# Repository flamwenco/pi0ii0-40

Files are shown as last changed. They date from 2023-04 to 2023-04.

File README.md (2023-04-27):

# pi0ii0-40
Open source, RP2040 based pcb for the [M0ii040](https://booth.pm/ja/items/4407257).

Supported layout options:

m0ii40layout

## Production files

The current version of this pcb that supports all above layouts has been ordered and confirmed to work, but I am not responsible for your orders with a pcb manu. No support will be provided, order at your own risk.

## Special Thanks
[SST60](https://github.com/dededecline/SST60), this project heavily lifts the rp2040 wiring from it

[marksard's](https://github.com/marksard/ms_m0ii040pcb) m0ii040 pcb, used to sanity check my edge cuts

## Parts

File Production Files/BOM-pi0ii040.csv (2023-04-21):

Comment | Designator | Footprint | LCSC
1k | R_Crystal1,R_Flash1,R_RST1 | R_0402_1005Metric | C11702
PRTR5V0U2X | U3 | SOT143B | C12333
.1u | C_1V-Decoup2,C_1V-Decoup3,C_3V-Decoup3,C_3V-Decoup4,C_3V-Decoup5,C_3V-Decoup6,C_3V-Decoup7,C_3V-Decoup8,C_3V-Decoup9,C_Flash1 | C_0402_1005Metric | C1525
10u | C_3V-Decoup1 | C_0402_1005Metric | C15525
22pF | C_Crystal1,C_Crystal2 | C_0402_1005Metric | C1555
HRO-TYPE-C-31-M-12 | USB1 | HRO-TYPE-C-31-M-12-Assembly | C165948
27 | R_DATA1,R_DATA2 | R_0402_1005Metric | C203147
RP2040 | U1 | RP2040-QFN-56 | C2040
4.7n | C_Shield1 | C_0402_1005Metric | C237221
5k1 | R_USB1,R_USB2 | R_0402_1005Metric | C25905
1M | R_Shield1 | R_0402_1005Metric | C26083
1u | C_1V-Decoup1,C_3V-Decoup2,C_LDO1,C_LDO2 | C_0402_1005Metric | C52923
XC6206PxxxMR | U4 | SOT-23 | C5446
D_Small | D1,D10,D11,D12,D13,D14,D15,D16,D17,D18,D19,D2,D20,D21,D22,D23,D24,D25,D26,D27,D28,D29,D3,D30,D31,D32,D33,D34,D35,D36,D37,D38,D39,D4,D40,D5,D6,D7,D8,D9 | D_SOD-123 | C64898
12MHz | Y1 | Crystal_SMD_3225-4Pin_3.2x2.5mm | C9002
W25Q128JVS | U2 | SOIC-8_5.23x5.23mm_P1.27mm | C97521
500mA | F1 | Fuse_0805_2012Metric

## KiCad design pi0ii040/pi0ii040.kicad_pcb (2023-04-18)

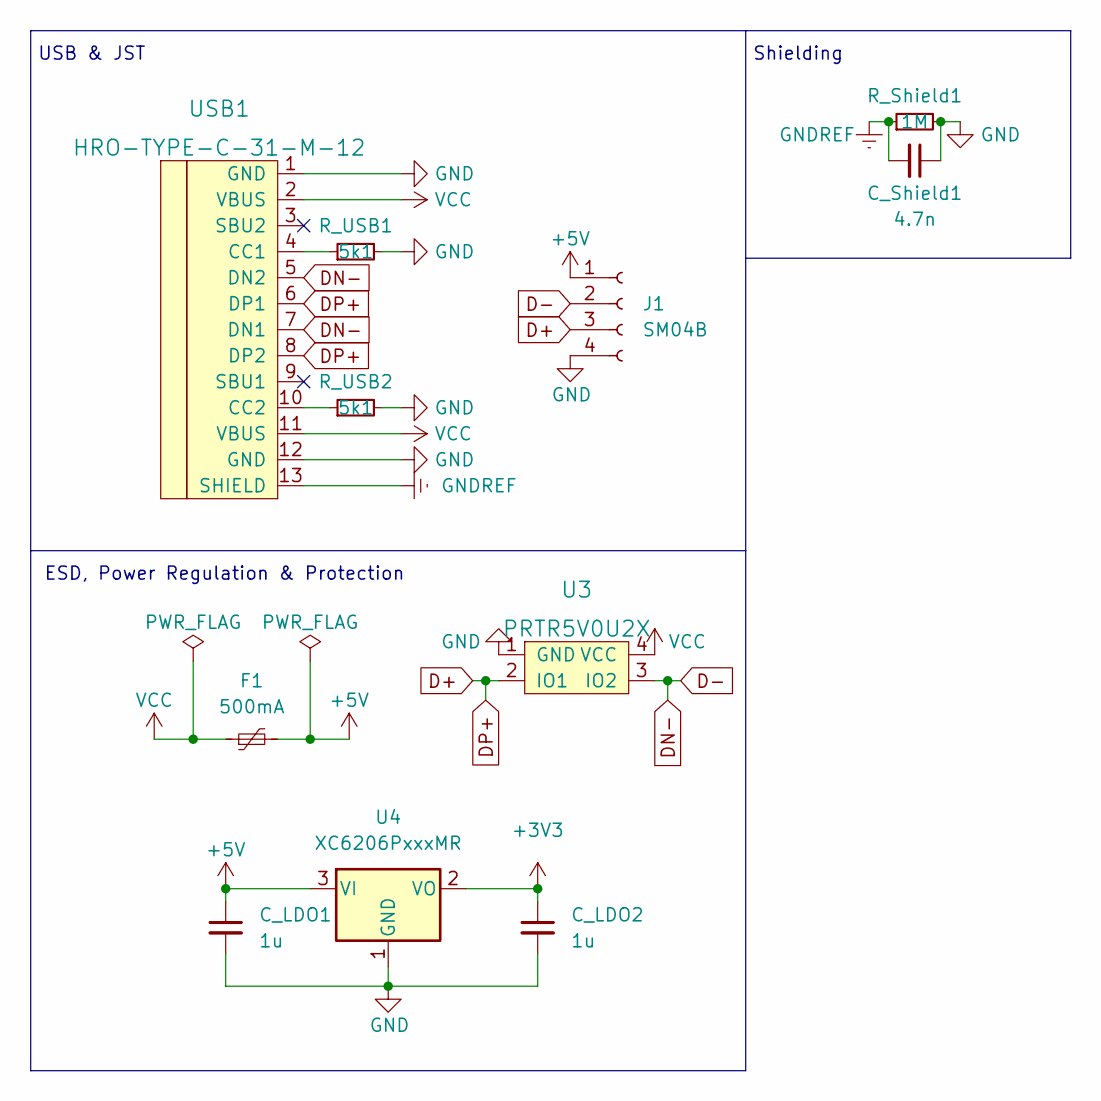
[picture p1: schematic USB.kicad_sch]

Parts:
C_LDO1, C_LDO2: 1u; C_0402_1005Metric
C_Shield1: 4.7n; C_0402_1005Metric
F1: 500mA; Fuse_0805_2012Metric
J1: SM04B; JST_SH_SM04B-SRSS-TB_1x04-1MP_P1.00mm_Horizontal
R_Shield1: 1M; R_0402_1005Metric
R_USB1, R_USB2: 5k1; R_0402_1005Metric
U3: PRTR5V0U2X; SOT143B
U4: XC6206PxxxMR; SOT-23
USB1: HRO-TYPE-C-31-M-12; HRO-TYPE-C-31-M-12-Assembly

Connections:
+3V3: C_LDO2.1, U4.2 (VO); also elsewhere on the board
+5V: C_LDO1.1, F1.2, J1.1, U4.3 (VI)
D+: J1.3, U3.2 (IO1), USB1.6 (DP1), USB1.8 (DP2); also elsewhere on the board
D-: J1.2, U3.3 (IO2), USB1.5 (DN2), USB1.7 (DN1); also elsewhere on the board
GND: C_LDO1.2, C_LDO2.2, C_Shield1.1, J1.4, R_Shield1.2, R_USB1.2, R_USB2.2, U3.1 (GND), U4.1 (GND), USB1.1 (GND), USB1.12 (GND); also elsewhere on the board
GNDREF: C_Shield1.2, R_Shield1.1, USB1.13 (SHIELD)
unnamed: R_USB1.1, USB1.4 (CC1)
unnamed: R_USB2.1, USB1.10 (CC2)
VCC: F1.1, U3.4 (VCC), USB1.2 (VBUS), USB1.11 (VBUS)

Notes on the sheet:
Shielding
ESD, Power Regulation & Protection
USB & JST

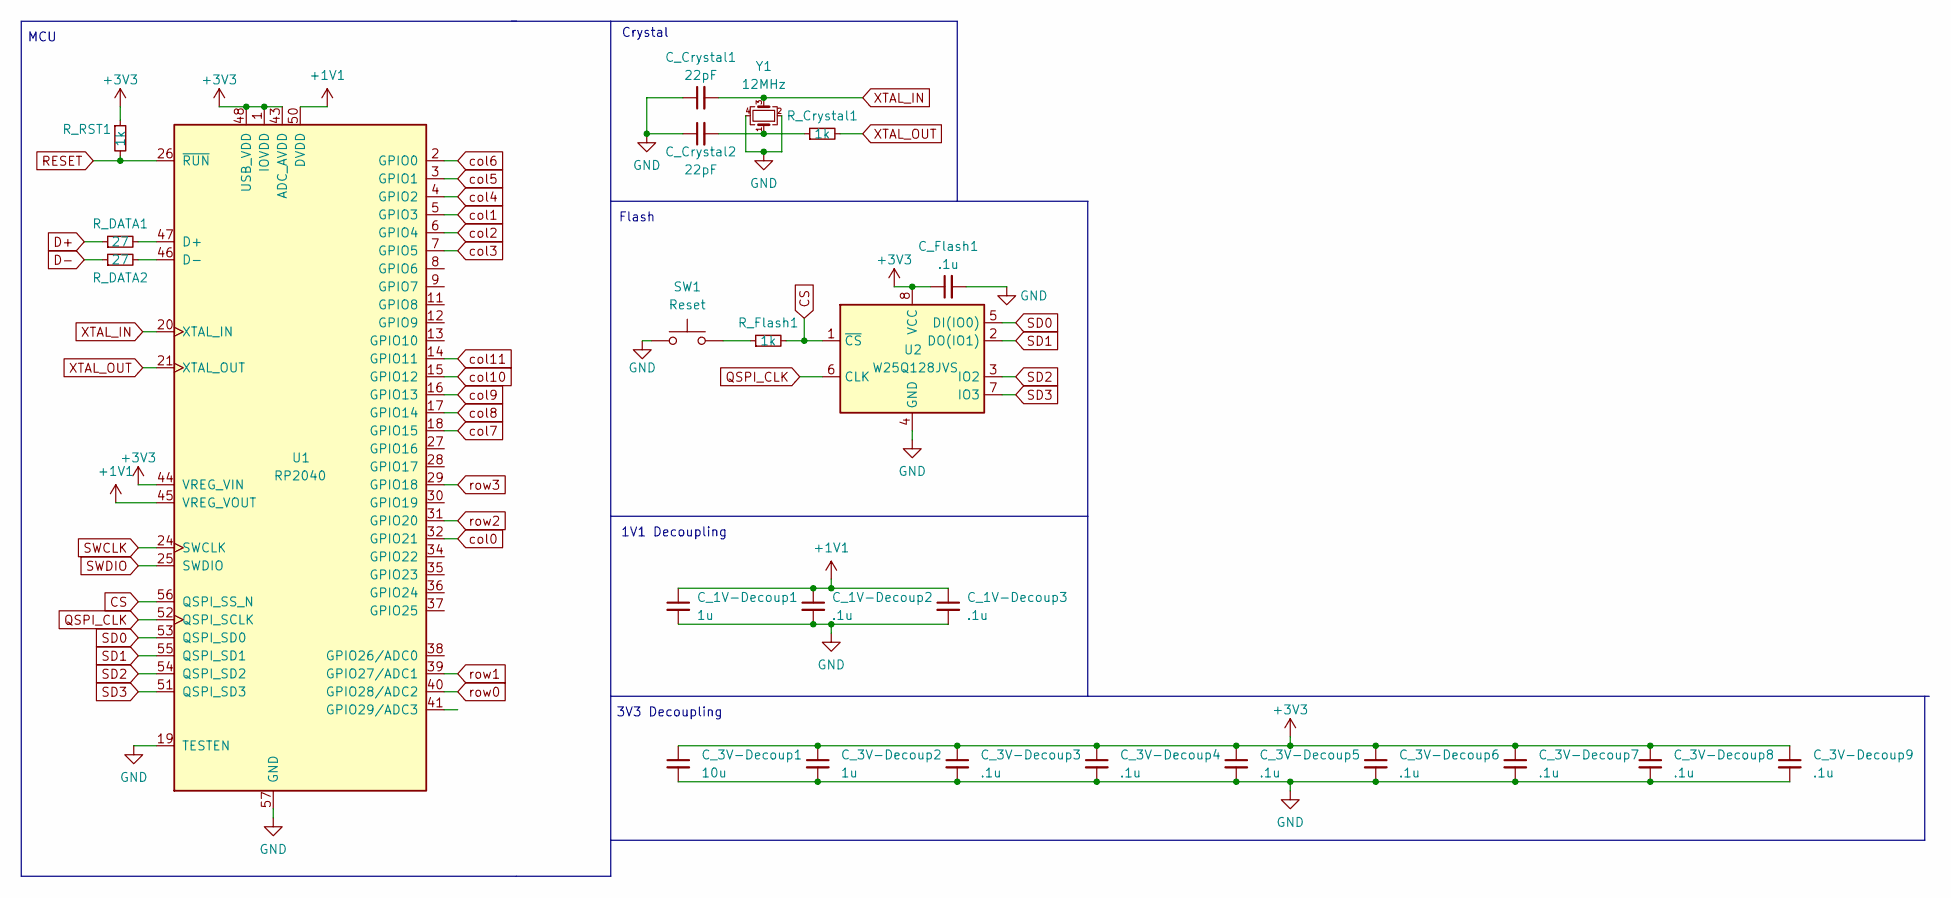
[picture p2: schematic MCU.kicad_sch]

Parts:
C_1V-Decoup1, C_3V-Decoup2: 1u; C_0402_1005Metric
C_1V-Decoup2, C_1V-Decoup3, C_3V-Decoup3, C_3V-Decoup4, C_3V-Decoup5, C_3V-Decoup6, C_3V-Decoup7, C_3V-Decoup8, C_3V-Decoup9: .1u; C_0402_1005Metric
C_3V-Decoup1: 10u; C_0402_1005Metric
C_Crystal1, C_Crystal2: 22pF; C_0402_1005Metric
C_Flash1: .1u; C_0402_1005Metric
R_Crystal1: 1k; R_0402_1005Metric
R_DATA1, R_DATA2: 27; R_0402_1005Metric
R_Flash1: 1k; R_0402_1005Metric
R_RST1: 1k; R_0402_1005Metric
SW1: Reset; PinHeader_1x02_P1.27mm_Vertical
U1: RP2040; RP2040-QFN-56
U2: W25Q128JVS; SOIC-8_5.23x5.23mm_P1.27mm
Y1: 12MHz; Crystal_SMD_3225-4Pin_3.2x2.5mm

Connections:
+1V1: C_1V-Decoup1.1, C_1V-Decoup2.1, C_1V-Decoup3.1, U1.23 (DVDD), U1.45 (VREG_VOUT), U1.50 (DVDD)
+3V3: C_3V-Decoup1.1, C_3V-Decoup2.1, C_3V-Decoup3.1, C_3V-Decoup4.1, C_3V-Decoup5.1, C_3V-Decoup6.1, C_3V-Decoup7.1, C_3V-Decoup8.1, C_3V-Decoup9.1, C_Flash1.1, R_RST1.1, U1.1 (IOVDD), U1.10 (IOVDD), U1.22 (IOVDD), U1.33 (IOVDD), U1.42 (IOVDD), U1.43 (ADC_AVDD), U1.44 (VREG_VIN), U1.48 (USB_VDD), U1.49 (IOVDD), U2.8 (VCC); also elsewhere on the board
CS: R_Flash1.2, U1.56 (QSPI_SS_N), U2.1 (~CS)
D+: R_DATA1.1; also elsewhere on the board
D-: R_DATA2.1; also elsewhere on the board
GND: C_1V-Decoup1.2, C_1V-Decoup2.2, C_1V-Decoup3.2, C_3V-Decoup1.2, C_3V-Decoup2.2, C_3V-Decoup3.2, C_3V-Decoup4.2, C_3V-Decoup5.2, C_3V-Decoup6.2, C_3V-Decoup7.2, C_3V-Decoup8.2, C_3V-Decoup9.2, C_Crystal1.1, C_Crystal2.1, C_Flash1.2, SW1.1, U1.19 (TESTEN), U1.57 (GND), U2.4 (GND), Y1.2, Y1.4; also elsewhere on the board
unnamed: C_Crystal2.2, R_Crystal1.1, Y1.1
unnamed: R_Flash1.1, SW1.2
unnamed: R_DATA1.2, U1.47 (D+)
unnamed: R_DATA2.2, U1.46 (D-)
QSPI_CLK: U1.52 (QSPI_SCLK), U2.6 (CLK)
RESET: R_RST1.2, U1.26 (~RUN); also elsewhere on the board
SD0: U1.53 (QSPI_SD0), U2.5 (DI(IO0))
SD1: U1.55 (QSPI_SD1), U2.2 (DO(IO1))
SD2: U1.54 (QSPI_SD2), U2.3 (IO2)
SD3: U1.51 (QSPI_SD3), U2.7 (IO3)
SWCLK: U1.24 (SWCLK); also elsewhere on the board
SWDIO: U1.25 (SWDIO); also elsewhere on the board
XTAL_IN: C_Crystal1.2, U1.20 (XTAL_IN), Y1.3
XTAL_OUT: R_Crystal1.2, U1.21 (XTAL_OUT)
col0: U1.32 (GPIO21); also elsewhere on the board
col1: U1.5 (GPIO3); also elsewhere on the board
col2: U1.6 (GPIO4); also elsewhere on the board
col3: U1.7 (GPIO5); also elsewhere on the board
col4: U1.4 (GPIO2); also elsewhere on the board
col5: U1.3 (GPIO1); also elsewhere on the board
col6: U1.2 (GPIO0); also elsewhere on the board
col7: U1.18 (GPIO15); also elsewhere on the board
col8: U1.17 (GPIO14); also elsewhere on the board
col9: U1.16 (GPIO13); also elsewhere on the board
col10: U1.15 (GPIO12); also elsewhere on the board
col11: U1.14 (GPIO11); also elsewhere on the board
row0: U1.40 (GPIO28/ADC2); also elsewhere on the board
row1: U1.39 (GPIO27/ADC1); also elsewhere on the board
row2: U1.31 (GPIO20); also elsewhere on the board
row3: U1.29 (GPIO18); also elsewhere on the board

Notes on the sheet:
1V1 Decoupling
MCU
3V3 Decoupling
Crystal
Flash

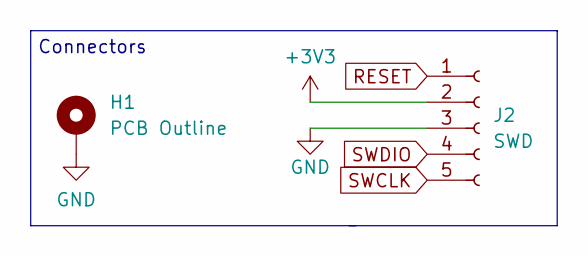
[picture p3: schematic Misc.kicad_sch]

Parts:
H1: PCB Outline; m0ii040_PCB_Template_v1.0.1
J2: SWD; PinHeader_1x05_P2.54mm_Vertical

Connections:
+3V3: J2.2; also elsewhere on the board
GND: H1.1, J2.3; also elsewhere on the board
RESET: J2.1; also elsewhere on the board
SWCLK: J2.5; also elsewhere on the board
SWDIO: J2.4; also elsewhere on the board

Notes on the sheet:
Connectors

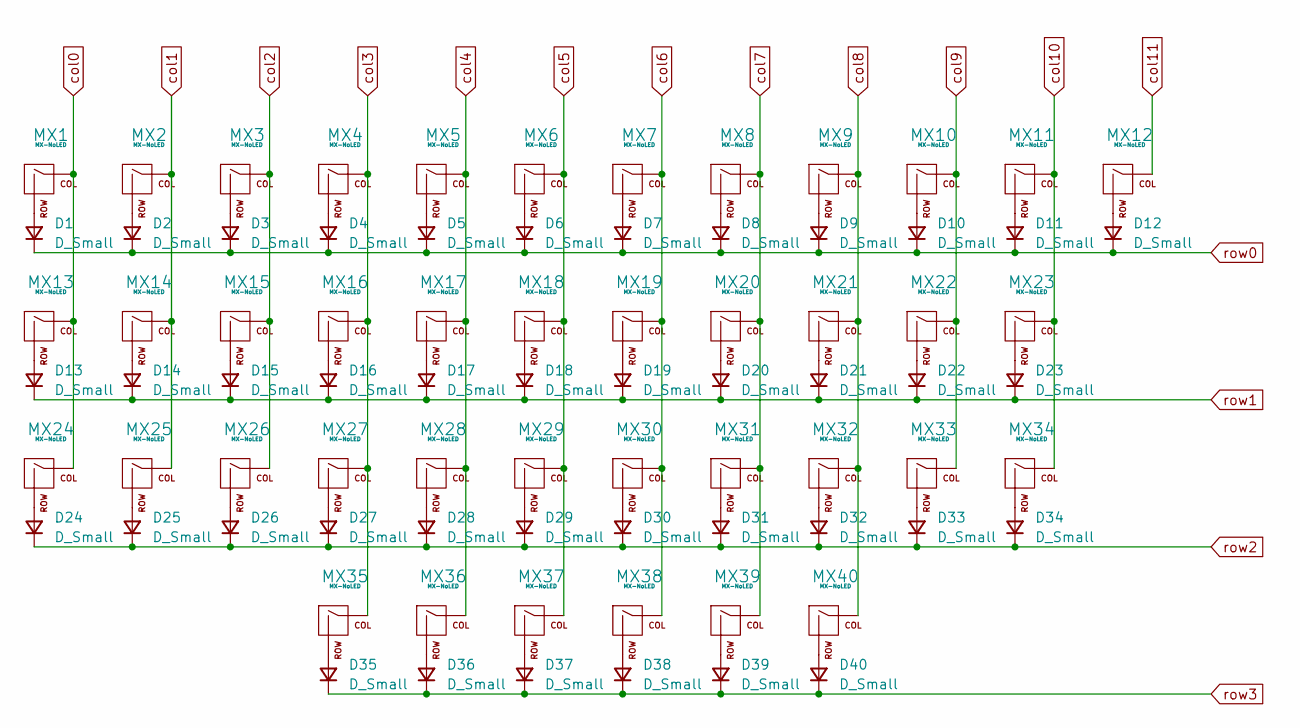
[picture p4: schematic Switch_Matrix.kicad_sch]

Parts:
D1, D2, D3, D4, D5, D6, D7, D8, D9, D10, D11, D12, D13, D14, D15, D16, D17, D18, D19, D20, D21, D22, D23, D24, D25, D26, D27, D28, D29, D30, D31, D32, D33, D34, D35, D36, D37, D38, D39, D40: D_Small; D_SOD-123
MX1, MX2, MX3, MX4, MX5, MX6, MX7, MX8, MX9, MX10, MX11, MX12, MX14, MX15, MX16, MX17, MX18, MX19, MX20, MX21, MX22, MX25, MX26, MX27, MX28, MX29, MX30, MX31, MX32, MX33, MX35, MX40: MX-NoLED; MXOnly-1U-NoLED
MX13, MX34, MX36, MX39: MX-NoLED; MXOnly-1.25U-NoLED
MX23, MX24: MX-NoLED; MXOnly-1.75U-NoLED
MX37: MX-NoLED; MXOnly-2.75U-ReversedStabilizers-NoLED
MX38: MX-NoLED; MXOnly-2.25U-ReversedStabilizers-NoLED

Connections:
unnamed: D1.2 (A), MX1.2 (ROW)
unnamed: D2.2 (A), MX2.2 (ROW)
unnamed: D3.2 (A), MX3.2 (ROW)
unnamed: D4.2 (A), MX4.2 (ROW)
unnamed: D5.2 (A), MX5.2 (ROW)
unnamed: D6.2 (A), MX6.2 (ROW)
unnamed: D7.2 (A), MX7.2 (ROW)
unnamed: D8.2 (A), MX8.2 (ROW)
unnamed: D9.2 (A), MX9.2 (ROW)
unnamed: D10.2 (A), MX10.2 (ROW)
unnamed: D11.2 (A), MX11.2 (ROW)
unnamed: D12.2 (A), MX12.2 (ROW)
unnamed: D13.2 (A), MX13.2 (ROW)
unnamed: D14.2 (A), MX14.2 (ROW)
unnamed: D15.2 (A), MX15.2 (ROW)
unnamed: D16.2 (A), MX16.2 (ROW)
unnamed: D17.2 (A), MX17.2 (ROW)
unnamed: D18.2 (A), MX18.2 (ROW)
unnamed: D19.2 (A), MX19.2 (ROW)
unnamed: D20.2 (A), MX20.2 (ROW)
unnamed: D21.2 (A), MX21.2 (ROW)
unnamed: D22.2 (A), MX22.2 (ROW)
unnamed: D23.2 (A), MX23.2 (ROW)
unnamed: D24.2 (A), MX24.2 (ROW)
unnamed: D25.2 (A), MX25.2 (ROW)
unnamed: D26.2 (A), MX26.2 (ROW)
unnamed: D27.2 (A), MX27.2 (ROW)
unnamed: D28.2 (A), MX28.2 (ROW)
unnamed: D29.2 (A), MX29.2 (ROW)
unnamed: D30.2 (A), MX30.2 (ROW)
unnamed: D31.2 (A), MX31.2 (ROW)
unnamed: D32.2 (A), MX32.2 (ROW)
unnamed 41: D33.2 (A), MX33.2 (ROW); also elsewhere on the board
unnamed 42: D34.2 (A), MX34.2 (ROW); also elsewhere on the board
unnamed 43: D35.2 (A), MX35.2 (ROW); also elsewhere on the board
unnamed: D36.2 (A), MX36.2 (ROW)
unnamed 45: D37.2 (A), MX37.2 (ROW); also elsewhere on the board
unnamed: D38.2 (A), MX38.2 (ROW)
unnamed: D39.2 (A), MX39.2 (ROW)
unnamed 48: D40.2 (A), MX40.2 (ROW); also elsewhere on the board
col0: MX1.1 (COL), MX13.1 (COL), MX24.1 (COL); also elsewhere on the board
col1: MX2.1 (COL), MX14.1 (COL), MX25.1 (COL); also elsewhere on the board
col2: MX3.1 (COL), MX15.1 (COL), MX26.1 (COL); also elsewhere on the board
col3: MX4.1 (COL), MX16.1 (COL), MX27.1 (COL), MX35.1 (COL); also elsewhere on the board
col4: MX5.1 (COL), MX17.1 (COL), MX28.1 (COL), MX36.1 (COL); also elsewhere on the board
col5: MX6.1 (COL), MX18.1 (COL), MX29.1 (COL), MX37.1 (COL); also elsewhere on the board
col6: MX7.1 (COL), MX19.1 (COL), MX30.1 (COL), MX38.1 (COL); also elsewhere on the board
col7: MX8.1 (COL), MX20.1 (COL), MX31.1 (COL), MX39.1 (COL); also elsewhere on the board
col8: MX9.1 (COL), MX21.1 (COL), MX32.1 (COL), MX40.1 (COL); also elsewhere on the board
col9: MX10.1 (COL), MX22.1 (COL), MX33.1 (COL); also elsewhere on the board
col10: MX11.1 (COL), MX23.1 (COL), MX34.1 (COL); also elsewhere on the board
col11: MX12.1 (COL); also elsewhere on the board
row0: D1.1 (K), D2.1 (K), D3.1 (K), D4.1 (K), D5.1 (K), D6.1 (K), D7.1 (K), D8.1 (K), D9.1 (K), D10.1 (K), D11.1 (K), D12.1 (K); also elsewhere on the board
row1: D13.1 (K), D14.1 (K), D15.1 (K), D16.1 (K), D17.1 (K), D18.1 (K), D19.1 (K), D20.1 (K), D21.1 (K), D22.1 (K), D23.1 (K); also elsewhere on the board
row2: D24.1 (K), D25.1 (K), D26.1 (K), D27.1 (K), D28.1 (K), D29.1 (K), D30.1 (K), D31.1 (K), D32.1 (K), D33.1 (K), D34.1 (K); also elsewhere on the board
row3: D35.1 (K), D36.1 (K), D37.1 (K), D38.1 (K), D39.1 (K), D40.1 (K); also elsewhere on the board

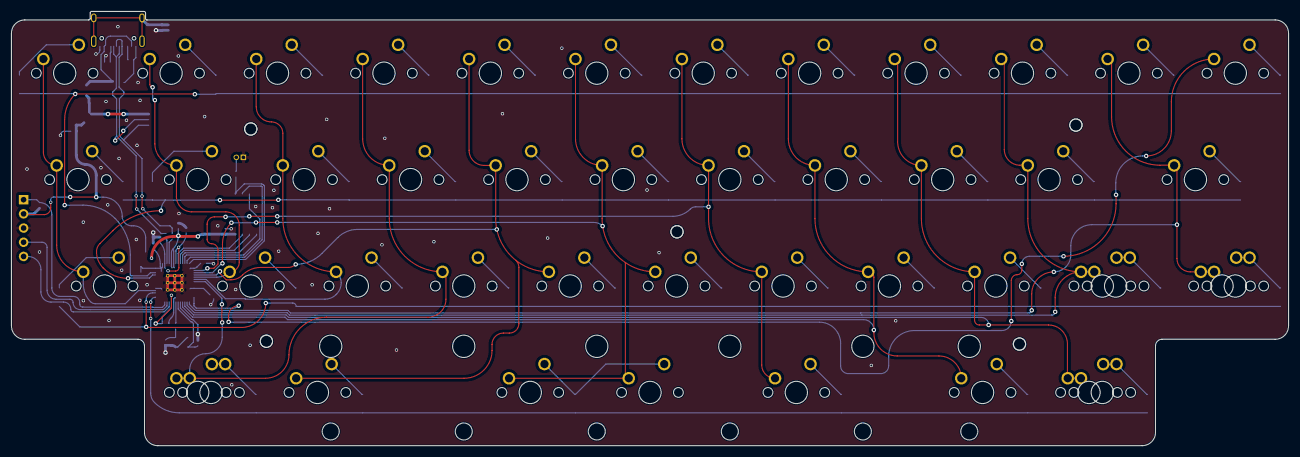
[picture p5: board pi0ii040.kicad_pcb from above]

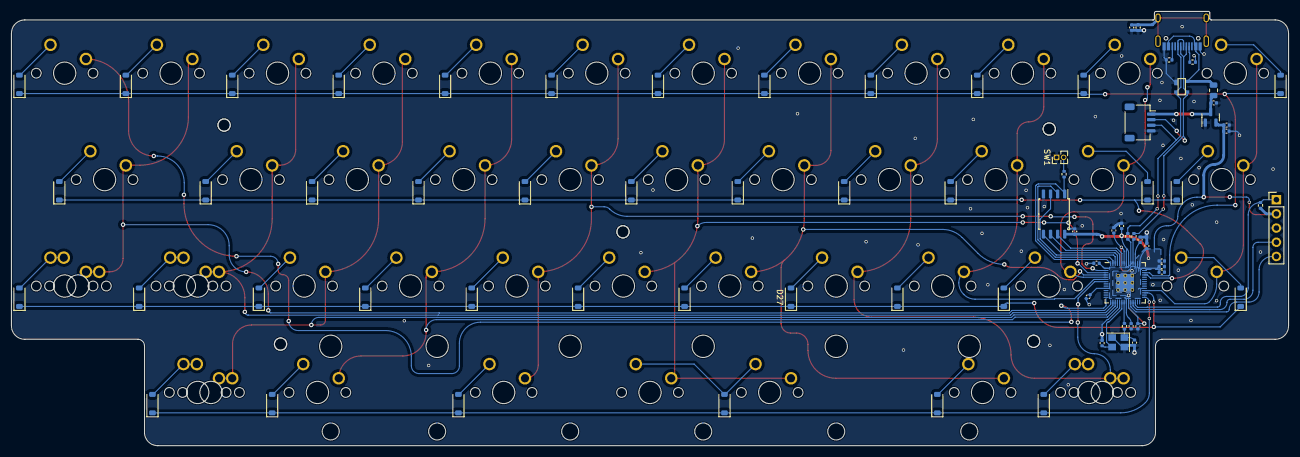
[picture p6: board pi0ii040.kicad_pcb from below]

Board: 2 copper layers, 228.6 x 77.7 mm, 122 parts (76 on the bottom side), 81 nets.

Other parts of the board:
MX33#2, MX34#2, MX35#2, MX40#2: MX-NoLED; MXOnly-1U-NoLED
MX37#2: MX-NoLED; MXOnly-2.75U-ReversedStabilizers-NoLED

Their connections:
unnamed 41: MX33#2.2 (ROW); also elsewhere on the board
unnamed 42: MX34#2.2 (ROW); also elsewhere on the board
unnamed 43: MX35#2.2 (ROW); also elsewhere on the board
unnamed 45: MX37#2.2 (ROW); also elsewhere on the board
unnamed 48: MX40#2.2 (ROW); also elsewhere on the board
col3: MX35#2.1 (COL); also elsewhere on the board
col5: MX37#2.1 (COL); also elsewhere on the board
col8: MX40#2.1 (COL); also elsewhere on the board
col9: MX33#2.1 (COL); also elsewhere on the board
col10: MX34#2.1 (COL); also elsewhere on the board

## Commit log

2023-04-17 Add submodules, start schematic
    [MCU.kicad_sch, Switch_Matrix.kicad_sch, USB.kicad_sch]
2023-04-18 Finish? pcb
    [MCU.kicad_sch, Misc.kicad_sch, Switch_Matrix.kicad_sch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]
2023-04-21 More pcb work and create plate
    [BOM-pi0ii040.csv, BOM-plate.csv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]
2023-04-27 Create production files folder
    [BOM-pi0ii040.csv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]
